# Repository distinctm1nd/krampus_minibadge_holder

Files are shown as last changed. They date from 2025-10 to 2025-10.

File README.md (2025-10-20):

# Krampus Minibadge Holder

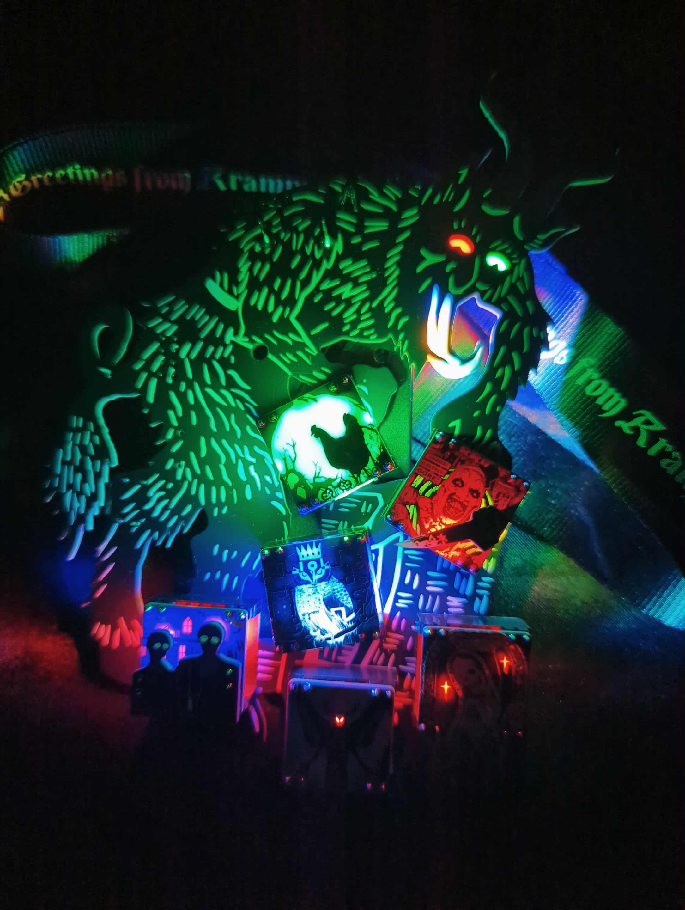
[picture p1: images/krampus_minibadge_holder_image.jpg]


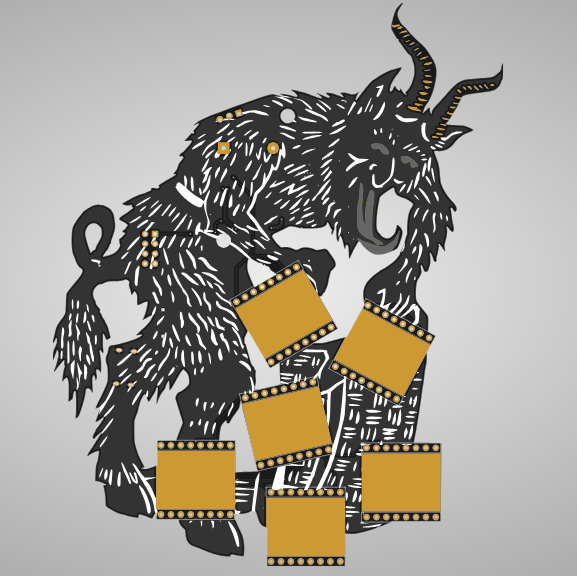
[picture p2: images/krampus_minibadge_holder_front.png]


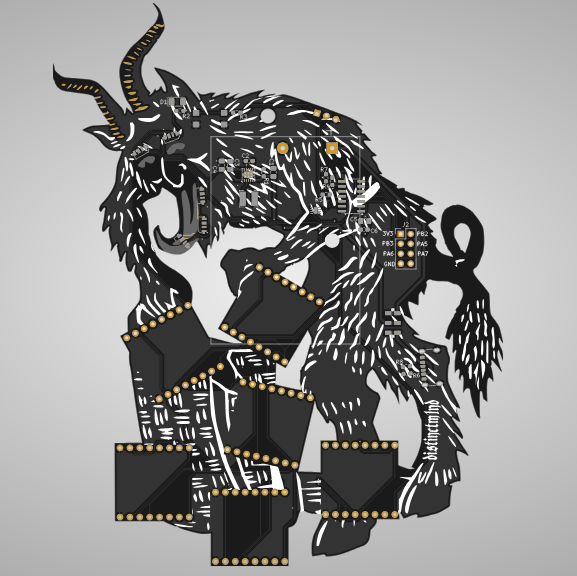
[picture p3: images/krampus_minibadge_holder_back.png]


The microcontroller is an ATtiny 814. Krampus has a small dev connector with 3V3, GND and the following GPIOs: PA5, PA6, PA7, PB2 and PB3. You can program using the 3-pin sneaky connector (doesn't require soldering). There are multiple ways to program so if you already have your method then you are good to go. If you have not programmed an ATtiny with UDPI then I recommend following the instructions located here to get started: <a href="https://wolles-elektronikkiste.de/en/using-megatinycore">https://wolles-elektronikkiste.de/en/using-megatinycore</a>. If you use the method described here with Arduino, you do not need to connect a resistor in series with pin 6 because this is already installed on the board.

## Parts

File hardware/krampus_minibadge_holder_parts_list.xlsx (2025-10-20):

Designator | Footprint | Value | Description | Manufacturer | Supplier | Part Number | Package | First Option
BT1 | BatteryHolder_Keystone_2479_3xAAA | Battery |  |  | Mouser |  |  | https://www.mouser.com/ProductDetail/Keystone-Electronics/2479?qs=Q3RoVmURDomBPD85HfXZoA%3D%3D
C1, C3, C4, C5 | 805 | 10uF |  |  | Mouser |  |  | https://www.mouser.com/ProductDetail/Samsung-Electro-Mechanics/CL21B106KPQNNNE?qs=yOVawPpwOwnw0R5uMCgpNQ%3D%3D
C2, C6 | 603 | 0.1uF |  |  | Mouser |  |  | https://www.mouser.com/ProductDetail/YAGEO/CC0603KRX5R9BB104?qs=vkMqrgFpRaiQQdJI9SHamg%3D%3D
D1 | 1206 | LED
D15, D17, D2, D24, D25 | sk6812-side-a | WS2812_4020 |  |  | LCSC |  |  | https://www.lcsc.com/product-detail/C5378721.html
J1 | USB_C_Receptacle_GCT_USB4125-xx-x-0190_6P_TopMnt_Horizontal | USB_C_Receptacle_USB2.0_14P |  |  | Mouser |  |  | https://www.mouser.com/ProductDetail/GCT/USB4125-GF-A-0190?qs=QNEnbhJQKvbCz4hEJBS24w%3D%3D
J2 | PinHeader_2x04_P2.54mm_Vertical |  | No Part Provided- for opt dev
J3 | night_evil_ai_updi | Conn_01x03_Pin | No Part Provided- for programming |  | None
L1 | L_Bourns-SRN4018 | SRN4018-2R2M |  |  | Mouser |  |  | https://www.mouser.com/ProductDetail/Bourns/SRN4018-2R2M?qs=UvjENeDOEeeZshE%252B%2FY2s8w%3D%3D
MB1, MB2, MB3, MB4, MB5, MB6 | MiniBadge_Slot_Reflective | MiniBadge_Full | 1x8 2.54 female header |  | Tayda
R1 | 0.0603 | 100 ohm
R2 | 0.0603 | 100 ohm
R3 | 0.0603 | 100k ohm
R4, R7 | 0.0603 | 4.7k ohm
R5 | 0.0603 | 220 ohm
R6, R8 | 0.0603 | 5.1k
SW1 | js202011jaqn | SW_DPDT |  |  | Digikey |  |  | https://www.digikey.com/en/products/detail/c-k/JS202011JAQN/6137629?s=N4IgTCBcDaIFYGcwAYUEY1wIYEcB2IAugL5A
SW2 | button_switch_TL3305A | SW_Push |  |  | Mouser |  |  | https://www.mouser.com/ProductDetail/E-Switch/TL3305AF160QG?qs=UrFqKgNWc7RTylqwItwDfw%3D%3D
U1 | SOIC-14_3.9x8.7mm_P1.27mm | ATtiny814-SS |  |  | Mouser |  |  | https://www.mouser.com/ProductDetail/Microchip-Technology/ATTINY814-SSN?qs=3HJ2avRr9PJL25ROxZVkTg%3D%3D
U3 | Texas_DRC0010J | TPS63001DRCR |  |  | Mouser |  |  | https://www.mouser.com/ProductDetail/Texas-Instruments/TPS63001DRCT?qs=7kv20MEVUlgqNQNnGuTeFA%3D%3D
U4 | DFN-8_ALM | A3910EEETR-T |  |  |  |  |  | https://www.mouser.com/ProductDetail/Allegro-MicroSystems/A3910EEETR-T?qs=pUKx8fyJudArirmzhZClvw%3D%3D
PCBs |  |  | PCB | JLCPCB | JLCPCB

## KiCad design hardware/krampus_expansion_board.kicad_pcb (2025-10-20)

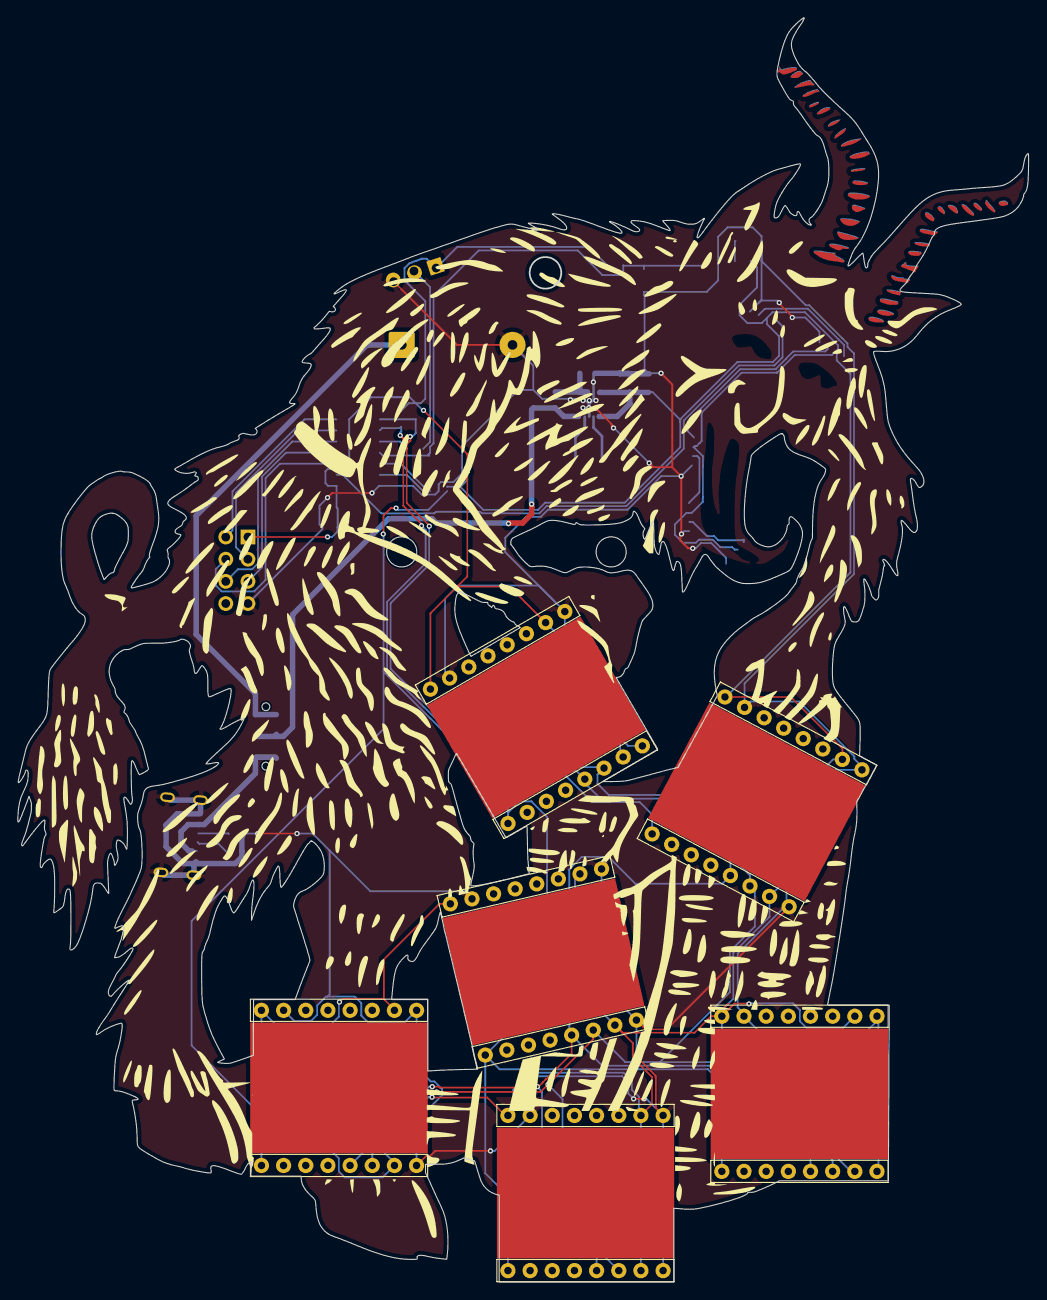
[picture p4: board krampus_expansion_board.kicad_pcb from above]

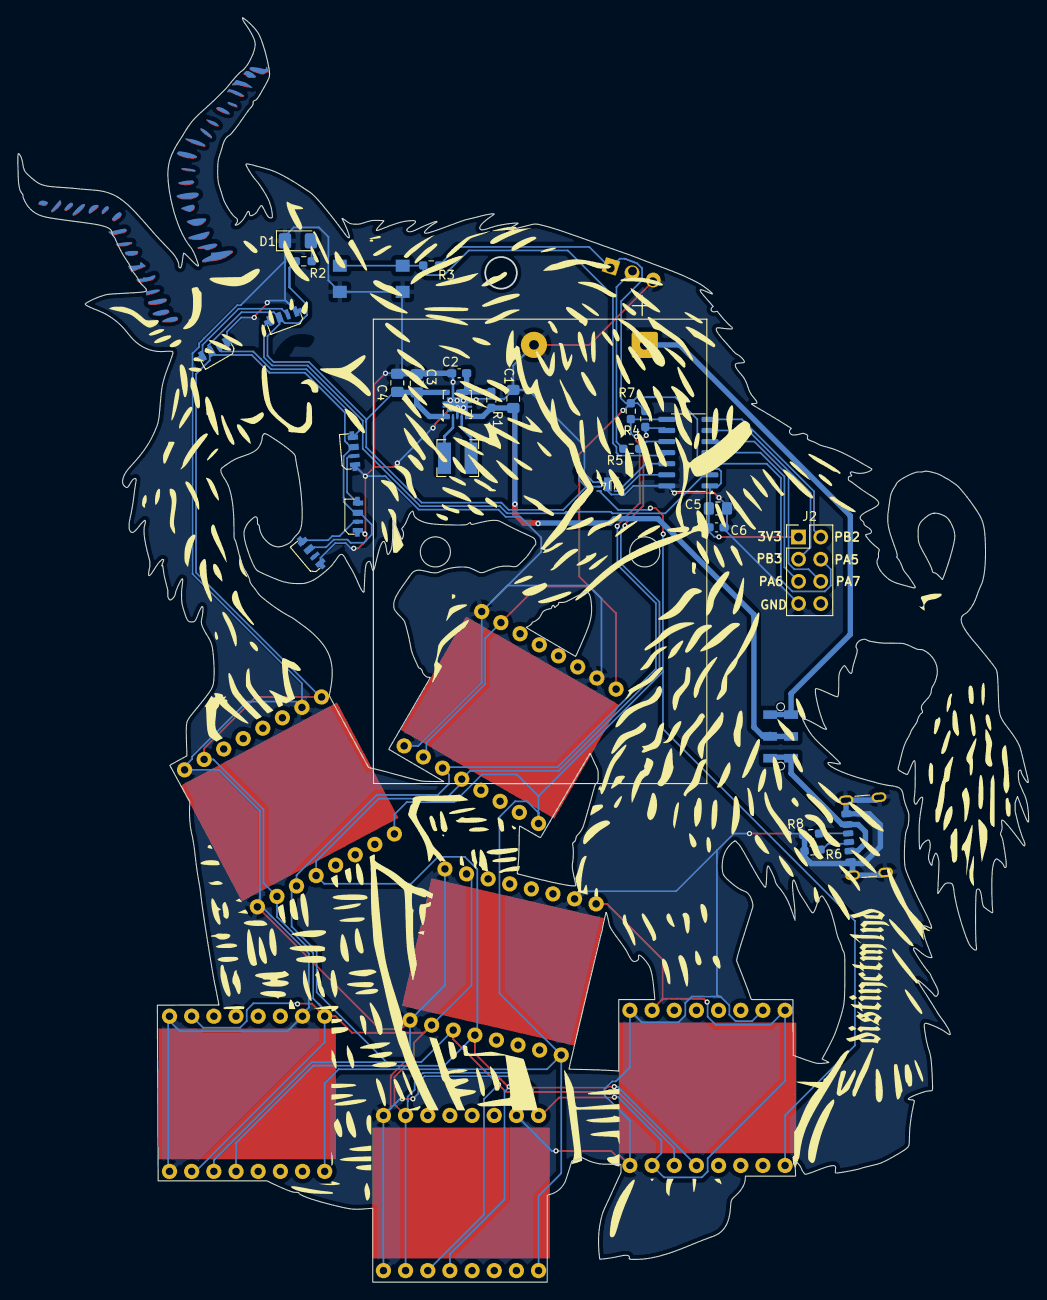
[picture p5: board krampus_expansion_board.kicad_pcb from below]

Board: 2 copper layers, 115.8 x 144.9 mm, 36 parts (30 on the bottom side), 29 nets.

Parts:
BT1: Battery; BatteryHolder_Keystone_2479_3xAAA
C1, C3, C4, C5: 10uF; C_0805_2012Metric_Pad1.18x1.45mm_HandSolder
C2, C6: 0.1uF; C_0603_1608Metric_Pad1.08x0.95mm_HandSolder
D1: LED; LED_1206_3216Metric_Pad1.42x1.75mm_HandSolder
D2, D15, D17, D24, D25: WS2812_4020; sk6812-side-a
J1: USB_C_Receptacle_USB2.0_14P; USB_C_Receptacle_GCT_USB4125-xx-x-0190_6P_TopMnt_Horizontal
J2: Conn_01x07_Pin; PinHeader_2x04_P2.54mm_Vertical
J3: Conn_01x03_Pin; night_evil_ai_updi
L1: SRN4018-2R2M; L_Bourns-SRN4018
MB1, MB2, MB3, MB4, MB5, MB6: MiniBadge_Full; MiniBadge_Slot_Reflective
R1: 100 ohm; R_0603_1608Metric_Pad0.98x0.95mm_HandSolder
R2: 15 ohm; R_0603_1608Metric_Pad0.98x0.95mm_HandSolder
R3: 100k ohm; R_0603_1608Metric_Pad0.98x0.95mm_HandSolder
R4, R7: 4.7k ohm; R_0603_1608Metric_Pad0.98x0.95mm_HandSolder
R5: 220 ohm; R_0603_1608Metric_Pad0.98x0.95mm_HandSolder
R6, R8: 5.1k; R_0603_1608Metric_Pad0.98x0.95mm_HandSolder
SW1: SW_DPDT; js202011jaqn
SW2: SW_Push; button_switch_TL3305A
U1: ATtiny814-SS; SOIC-14_3.9x8.7mm_P1.27mm
U3: TPS63001DRCR; Texas_DRC0010J
U4: A3910EEETR-T; DFN-8_ALM

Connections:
+3V3: C3.1, C4.1, C5.1, C6.1, D2.2 (VDD), D15.2 (VDD), D17.2 (VDD), D24.2 (VDD), D25.2 (VDD), J2.1, J3.1, MB1.1 (+VBATT), MB1.7 (+3V3), MB1.15 (3V3+), MB2.1 (+VBATT), MB2.7 (+3V3), MB2.15 (3V3+), MB3.1 (+VBATT), MB3.7 (+3V3), MB3.15 (3V3+), MB4.1 (+VBATT), MB4.7 (+3V3), MB4.15 (3V3+), MB5.1 (+VBATT), MB5.7 (+3V3), MB5.15 (3V3+), MB6.1 (+VBATT), MB6.7 (+3V3), MB6.15 (3V3+), R2.1, R3.1, R4.1, R7.1, U1.1 (VCC), U3.1 (VOUT), U3.10 (FB), U4.7 (VBB)
BATT: BT1.1 (+), SW1.3 (C)
BUTTON: R3.2, SW2.1, U1.11 (PA1)
GND: BT1.2 (-), C1.2, C2.2, C3.2, C4.2, C5.2, C6.2, D1.1 (K), D2.4 (VSS), D15.4 (VSS), D17.4 (VSS), D24.4 (VSS), D25.4 (VSS), J1.A12 (GND), J1.B12 (GND), J1.S1 (SHIELD), J2.7, J3.3, MB1.2 (GND), MB1.8 (GND), MB1.16 (GND), MB2.2 (GND), MB2.8 (GND), MB2.16 (GND), MB3.2 (GND), MB3.8 (GND), MB3.16 (GND), MB4.2 (GND), MB4.8 (GND), MB4.16 (GND), MB5.2 (GND), MB5.8 (GND), MB5.16 (GND), MB6.2 (GND), MB6.8 (GND), MB6.16 (GND), R6.1, R8.1, SW2.2, U1.14 (GND), U3.3 (PGND), U3.9 (GND), U3.11 (PAD), U4.6 (GND), U4.9 (EPAD)
LED_ARRAY: D15.1 (DIN), U1.2 (PA4)
MB_CLOCK: MB1.9 (CLK), MB2.9 (CLK), MB3.9 (CLK), MB4.9 (CLK), MB5.9 (CLK), MB6.9 (CLK), U4.8 (OUT1)
MB_CLOCK_H: U1.13 (PA3), U4.1 (HIN1)
MB_CLOCK_L: U1.12 (PA2), U4.2 (LIN1)
unnamed: D1.2 (A), R2.2
unnamed: D2.1 (DIN), D25.3 (DOUT)
unnamed: D15.3 (DOUT), D17.1 (DIN)
unnamed: D17.3 (DOUT), D24.1 (DIN)
unnamed: D24.3 (DOUT), D25.1 (DIN)
unnamed: J1.A5 (CC1), R6.2
unnamed: J1.B5 (CC2), R8.2
unnamed: C1.1, R1.1, SW1.2 (B), U3.5 (VIN)
unnamed: R5.2, U1.10 (~RESET/PA0)
unnamed: C2.1, R1.2, U3.6 (EN), U3.7 (PS_SYNC), U3.8 (VINA)
unnamed: L1.1, U3.4 (L1)
unnamed: L1.2, U3.2 (L2)
PA5: J2.4, U1.3 (PA5)
PA6: J2.5, U1.4 (PA6)
PA7: J2.6, U1.5 (PA7)
PB2: J2.2, U1.7 (PB2)
PB3: J2.3, U1.6 (PB3)
SCL: MB1.13 (SCL), MB2.13 (SCL), MB3.13 (SCL), MB4.13 (SCL), MB5.13 (SCL), MB6.13 (SCL), R4.2, U1.9 (PB0)
SDA: MB1.14 (SDA), MB2.14 (SDA), MB3.14 (SDA), MB4.14 (SDA), MB5.14 (SDA), MB6.14 (SDA), R7.2, U1.8 (PB1)
UPDI: J3.2, R5.1
VBUS: J1.A9 (VBUS), J1.B9 (VBUS), SW1.1 (A)

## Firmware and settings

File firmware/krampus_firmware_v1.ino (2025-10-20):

#include <avr/io.h>
#include <util/delay.h>

#define EYE_TONGUE_LED_ARRAY 4    
#define NUM_EYE_TONGUE_LEDS 5       
#define BUTTON_PIN 1         
#define MINIBADGE_CLK_CTRL_H_PIN 3 
#define MINIBADGE_CLK_CTRL_L_PIN 2 

enum LedMode {
    KRAMPUS_NIGHT, 
    GREETINGS_FROM_KRAMPUS,   
    STEALING_YOUR_MINIBADGES,  
    FEAR_IS_PRICE_FOR_CHEER,    
    SNOWY_NIGHT,   
    DEADLY_NIGHT,
    KRAMPUS_IS_SANTA,
    ALL_IS_CALM, 
    SLAY_BELLS,
    IN_THE_SHADOWS
};

LedMode currentMode = SLAY_BELLS; // Set default mode

void krampusNightLedMode(uint8_t index, uint8_t& g, uint8_t& r, uint8_t& b) {
    switch (index % 5) {
        case 0: // Light Red
            g = 0; 
            r = 200; 
            b = 0; 
            break;
        case 1: // Bright Red
            g = 0; 
            r = 255;
            b = 0; 
            break;
        case 2: // Light Brown
            g = 165; 
            r = 90; 
            b = 0; 
            break;
        case 3: // Dark Brown
            g = 75;  
            r = 40; 
            b = 0; 
            break;
        case 4: // Yellow
            g = 255; 
            r = 255; 
            b = 0; 
            break;
    }
}


void greetingsFromKrampusLedMode(uint8_t index, uint8_t& g, uint8_t& r, uint8_t& b) {
    switch (index % 5) {
        case 0: // Light Red
            g = 0;
            r = 200;                        
            b = 0;             
            break;
        case 1: // Medium Red
            g = 0;
            r = 255;                        
            b = 0;             
            break;
        case 2: // Dark Red
            g = 0;
            r = 150;                        
            b = 0;             
            break;
        case 3: // Deep Red
            g = 0;
            r = 100;                        
            b = 0;             
            break;
        case 4: // Yellow
            g = 255; 
            r = 255;                     
            b = 0;             
            break;
    }
}


void fearIsPriceOfCheerLedMode(uint8_t index, uint8_t& g, uint8_t& r, uint8_t& b) {
    switch (index % 5) {
        case 0: // Light Purple
            g = 128;
            r = 0;    
            b = 255;          
            break;
        case 1: // Dark Purple
            g = 75;
            r = 0;    
            b = 150;          
            break;
        case 2: // Light Blue
            g = 0;
            r = 0;    
            b = 200;          
            break;
        case 3: // Dark Blue
            g = 0;
            r = 0;    
            b = 100;          
            break;
        case 4: // Red
            g = 0;
            r = 255;    
            b = 0;            
            break;
    }
}


void stealingYourMinibadgesLedMode(uint8_t index, uint8_t& g, uint8_t& r, uint8_t& b) {
    switch (index % 5) {
        case 0: // Light Green
            g = 200;
            r = 0;   
            b = 0;  
            break;
        case 1: // Medium Light Green
            g = 150; 
            r = 0;  
            b = 0;  
            break;
        case 2: // Medium Green
            g = 100; 
            r = 0;   
            b = 0;   
            break;
        case 3: // Dark Green
            g = 50;  
            r = 0;   
            b = 0;   
            break;
        case 4: // Yellow-Green
            g = 255;
            r = 255; 
            b = 0;  
            break;
    }
}


void snowyNightLedMode(uint8_t index, uint8_t& g, uint8_t& r, uint8_t& b) {
    switch (index % 5) {
        case 0: // Light Purple
            g = 128; 
            r = 64;  
            b = 128; 
            break;
        case 1: // Dark Purple
            g = 0;   
            r = 0;   
            b = 255; 
            break;
        case 2: // Light Blue
            g = 0;   
            r = 0;  
            b = 200; 
            break;
        case 3: // Dark Blue
            g = 0;   
            r = 0;   
            b = 100; 
            break;
        case 4: // White
            g = 255; 
            r = 255; 
            b = 255; 
            break;
    }
}


void deadlyNightLedMode(uint8_t index, uint8_t& g, uint8_t& r, uint8_t& b) {
    switch (index % 5) {
        case 0: // Bright Red
            g = 0; 
            r = 255; 
            b = 0; 
            break;
        case 1: // Medium Red
            g = 0; 
            r = 200; 
            b = 0; 
            break;
        case 2: // Dark Red
            g = 0; 
            r = 150; 
            b = 0; 
            break;
        case 3: // Deeper Red
            g = 0; 
            r = 100;
            b = 0; 
            break;
        case 4: // Dark Brown
            g = 10;  
            r = 40;  
            b = 0;  
            break;
    }
}


void krampusIsSantaLedMode(uint8_t index, uint8_t& g, uint8_t& r, uint8_t& b) {
    switch (index % 4) {
        case 0: // Light Orange
            g = 165; 
            r = 255; 
            b = 0; 
            break;  
        case 1: // Medium Orange
            g = 140; 
            r = 255; 
            b = 0; break;  
        case 2: // Dark Orange
            g = 100; 
            r = 200; 
            b = 0; break;  
        case 3: // White
            g = 255; 
            r = 255; 
            b = 255; 
            break; 
    }
}

void allIsCalmLedMode(uint8_t index, uint8_t& g, uint8_t& r, uint8_t& b) {
    switch (index % 5) {
        case 0: // Red
            g = 0; 
            r = 255; 
            b = 0; 
            break;
        case 1: // Yellow
            g = 255; 
            r = 255; 
            b = 0; 
            break;
        case 2: // Orange
            g = 165; 
            r = 255; 
            b = 0; 
            break;
        case 3: // Green
            g = 0; 
            r = 255; 
            b = 0; 
            break;
        case 4: // Purple
            g = 128; 
            r = 0; 
            b = 128; 
            break;
    }
}

void slayBellsLedMode(uint8_t index, uint8_t& g, uint8_t& r, uint8_t& b) {
    switch (index % 5) {
        case 0: // Red
            g = 0; 
            r = 255; 
            b = 0; 
            break;
        case 1: // Green
            g = 255; 
            r = 0; 
            b = 0; 
            break;
        case 2: // Blue
            g = 0; 
            r = 0; 
            b = 255; 
            break;
        case 3: // Orange
            g = 165; 
            r = 255; 
            b = 0; 
            break;
        case 4: // Purple
            g = 128; 
            r = 0; 
            b = 128; 
            break;
    }
}

void inTheShadowsLedMode(uint8_t index, uint8_t& g, uint8_t& r, uint8_t& b) {
    switch (index % 5) {
        case 0: // Light Blue
            g = 0; 
            r = 0; 
            b = 255; 
            break;
        case 1: // Medium Blue
            g = 0; 
            r = 0; 
            b = 200; 
            break;
        case 2: // Dark Blue
            g = 0; 
            r = 0; 
            b = 100; 
            break;
        case 3: // Deep Blue
            g = 0; 
            r = 0; 
            b = 50; 
            break;
        case 4: // White
            g = 255; 
            r = 255; 
            b = 255;
            break;
    }
}


void sendColor(uint8_t g, uint8_t r, uint8_t b, uint8_t ledPin) {
    sendByte(g, ledPin);
    sendByte(r, ledPin);
    sendByte(b, ledPin);
}

void sendByte(uint8_t byte, uint8_t ledPin) {
    for (int i = 0; i < 8; i++) {
        if (byte & (1 << (7 - i))) {
            PORTA.OUTSET = (1 << ledPin);
            _delay_us(0.4);
            PORTA.OUTCLR = (1 << ledPin);
            _delay_us(0.85); 
        } else {
            PORTA.OUTSET = (1 << ledPin);
            _delay_us(0.2); 
            PORTA.OUTCLR = (1 << ledPin);
            _delay_us(0.9); 
        }
    }
}

void colorWipe(uint8_t green, uint8_t red, uint8_t blue, uint8_t ledPin, uint8_t numLeds) {
    for (int i = 0; i < numLeds; i++) {
        sendColor(green, red, blue, ledPin); 
        _delay_us(500); 
    }
}

void setup() {
    // Set eye_led_array and letter_led_array as output
    PORTA.DIRSET =  (1 << EYE_TONGUE_LED_ARRAY);
    
    // Set button pin as input with pull-up resistor
    PORTA.DIRCLR = (1 << BUTTON_PIN);
    PORTA.OUTSET = (1 << BUTTON_PIN); 

    // Set minibadge clock pins as output
    PORTA.DIRSET = (1 << MINIBADGE_CLK_CTRL_H_PIN) | (1 << MINIBADGE_CLK_CTRL_L_PIN);
    
    // Ensure all LEDs are off at the start
    colorWipe(0, 0, 0, EYE_TONGUE_LED_ARRAY, NUM_EYE_TONGUE_LEDS);
    _delay_ms(100);
}

bool isButtonPressed() {
    return (PORTA.IN & (1 << BUTTON_PIN)) == 0;
}

void updateMinibadgeClock() {
    if (PORTA.IN & (1 << MINIBADGE_CLK_CTRL_H_PIN)) {
        PORTA.OUTCLR = (1 << MINIBADGE_CLK_CTRL_H_PIN);
        PORTA.OUTSET = (1 << MINIBADGE_CLK_CTRL_L_PIN); 
    } else {
        PORTA.OUTSET = (1 << MINIBADGE_CLK_CTRL_H_PIN); 
        PORTA.OUTCLR = (1 << MINIBADGE_CLK_CTRL_L_PIN); 
    }
}

void loop() {
    static uint32_t lastClockUpdate = 0;
    const uint32_t clockUpdateInterval = 1000; // 1 second
    static uint8_t ledIndex = 0;
    static uint32_t lastUpdateTime = 0;
    const uint32_t updateInterval = 200; 

    // Check if it's time to update the LED colors
    if (millis() - lastUpdateTime >= updateInterval) {
        lastUpdateTime = millis();

        uint8_t green, red, blue;

        // Update the color for the current LED based on the mode
        switch (currentMode) {
            case KRAMPUS_NIGHT:
                krampusNightLedMode(ledIndex, green, red, blue);
                break;
            case GREETINGS_FROM_KRAMPUS:
                greetingsFromKrampusLedMode(ledIndex, green, red, blue);
                break;
            case STEALING_YOUR_MINIBADGES:
                fearIsPriceOfCheerLedMode(ledIndex, green, red, blue);
                break;
            case FEAR_IS_PRICE_FOR_CHEER:
                stealingYourMinibadgesLedMode(ledIndex, green, red, blue);
                break;
            case SNOWY_NIGHT:
                snowyNightLedMode(ledIndex, green, red, blue);
                break;
            case DEADLY_NIGHT:
                deadlyNightLedMode(ledIndex, green, red, blue);
                break;
            case KRAMPUS_IS_SANTA: 
                krampusIsSantaLedMode(ledIndex, green, red, blue);
                break;
            case ALL_IS_CALM: 
                allIsCalmLedMode(ledIndex, green, red, blue);
                break;
            case SLAY_BELLS:
                slayBellsLedMode(ledIndex, green, red, blue);
                break;
            case IN_THE_SHADOWS: 
                inTheShadowsLedMode(ledIndex, green, red, blue);
                break;
        }

        // Light up the current LED
        sendColor(green, red, blue, EYE_TONGUE_LED_ARRAY); 
        _delay_us(500); 

       

        // Update all previous LEDs to maintain their color
        for (uint8_t i = 0; i < NUM_EYE_TONGUE_LEDS; i++) {
            uint8_t prevGreen, prevRed, prevBlue;
            switch (currentMode) {
                case KRAMPUS_NIGHT:
                    krampusNightLedMode(((i + ledIndex) * 256 / NUM_EYE_TONGUE_LEDS) % 256, prevGreen, prevRed, prevBlue);
                    break;
                case GREETINGS_FROM_KRAMPUS:
                    greetingsFromKrampusLedMode(((i + ledIndex) * 256 / NUM_EYE_TONGUE_LEDS) % 256, prevGreen, prevRed, prevBlue);
                    break;
                case STEALING_YOUR_MINIBADGES:
                    fearIsPriceOfCheerLedMode(((i + ledIndex) * 256 / NUM_EYE_TONGUE_LEDS) % 256, prevGreen, prevRed, prevBlue);
                    break;
                case FEAR_IS_PRICE_FOR_CHEER:
                    stealingYourMinibadgesLedMode(((i + ledIndex) * 256 / NUM_EYE_TONGUE_LEDS) % 256, prevGreen, prevRed, prevBlue);
                    break;
                case SNOWY_NIGHT:
                    snowyNightLedMode(((i + ledIndex) * 256 / NUM_EYE_TONGUE_LEDS) % 256, prevGreen, prevRed, prevBlue);
                    break;
                case DEADLY_NIGHT:
                    deadlyNightLedMode(((i + ledIndex) * 256 / NUM_EYE_TONGUE_LEDS) % 256, prevGreen, prevRed, prevBlue);
                    break;
                case KRAMPUS_IS_SANTA: 
                    krampusIsSantaLedMode(((i + ledIndex) * 256 / NUM_EYE_TONGUE_LEDS) % 256, prevGreen, prevRed, prevBlue);
                    break;
                case ALL_IS_CALM: 
                    allIsCalmLedMode(((i + ledIndex) * 256 / NUM_EYE_TONGUE_LEDS) % 256, prevGreen, prevRed, prevBlue);
                    break;
                case SLAY_BELLS: 
                    slayBellsLedMode(((i + ledIndex) * 256 / NUM_EYE_TONGUE_LEDS) % 256, prevGreen, prevRed, prevBlue);
                    break;
                case IN_THE_SHADOWS: 
                    inTheShadowsLedMode(((i + ledIndex) * 256 / NUM_EYE_TONGUE_LEDS) % 256, prevGreen, prevRed, prevBlue);
                    break;
            }
            sendColor(prevGreen, prevRed, prevBlue, EYE_TONGUE_LED_ARRAY); 
        }

        // Update LED index for the next iteration
        ledIndex = (ledIndex + 1) % NUM_EYE_TONGUE_LEDS;
    }

    // Button logic for mode change
    if (isButtonPressed()) {
        currentMode = static_cast<LedMode>((currentMode + 1) % 10); 
        _delay_ms(300); 
    }

    // Re-check the minibadge clock update
    if (millis() - lastClockUpdate >= clockUpdateInterval) {
        updateMinibadgeClock();
        lastClockUpdate = millis();
    }
}
